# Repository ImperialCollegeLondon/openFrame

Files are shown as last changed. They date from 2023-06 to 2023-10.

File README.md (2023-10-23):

# Introduction to _openFrame_

This repository hosts information and instructions associated with the modular _openFrame_ microscope, a cost-effective platform based on open-hardware core components that can be configured or adapted to most light microscopy techniques and is intended to be used with open-source software, making instruments straightforward to maintain and to upgrade. _openFrame_ microscopes are based on stackable cylindrical aluminium layers centred on an optical axis that can accommodate a range of generic or specialised microscope components and which are ready to be mounted to external components such as optical cage systems. 
We are licensing the core _openFrame_ components under under the permissive version of the CERN Open Hardware License Version 2 ([https://ohwr.org/cern_ohl_p_v2.pdf](https://ohwr.org/cern_ohl_p_v2.pdf)), including the component designs hosted on this repository. We do not wish to restrict users in their ability to utilise _openFrame_ components and, as well as supporting the assembly of open instrumentation, openFrame components can be used with closed-source and proprietary technologies

Please see the ["How to cite openFrame" file](https://github.com/ImperialCollegeLondon/openFrame/blob/main/HOW%20TO%20CITE%20OPENFRAME.md) for information on how to cite _openFrame_

For further information on the modules that make up openFrame and associated information, please check the [wiki](https://github.com/ImperialCollegeLondon/openFrame/wiki) for this repository. 

## Where to find information

### [CAD designs](https://github.com/ImperialCollegeLondon/openFrame/tree/main/openFrame%20CAD)
The CAD files for the _openFrame_ components licensed under the permissive version of the CERN Open Hardware License Version 2 can be found in the folder called [_openFrame_ CAD](https://github.com/ImperialCollegeLondon/openFrame/tree/main/openFrame%20CAD). The [_openFrame_ part description PDFs](https://github.com/ImperialCollegeLondon/openFrame/tree/main/openFrame%20part%20description%20PDFs) folder contains important information such as hole tapping data, as well as suggested specification information relevant for fabrication of these components. 

### [Assembly instructions](https://github.com/ImperialCollegeLondon/openFrame/wiki)
As they become available, assembly instructions for creating an openFrame-based epifluorescence microscope will be found in the [wiki](https://github.com/ImperialCollegeLondon/openFrame/wiki) for this repo. Please note that as the system is modular and extensible, a much larger range of configurations are possible, but it is not feasible to document the assembly of every possible permutation. 

### Software
We make extensive use of [Micro-Manager](https://micro-manager.org/Version_2.0) to control _openFrame_ instrumentation but understand that this may not always be the first choice of all users or developers. Micro-Manager uses the Lesser GPL license ([https://www.gnu.org/licenses/lgpl-3.0.en.html](https://www.gnu.org/licenses/lgpl-3.0.en.html)) for its core and the BSD 2-clause license ([https://opensource.org/license/bsd-2-clause/](https://opensource.org/license/bsd-2-clause/)) for the GUI and device adapters, and any 
Micro-Manager device adapters we have written (for the openFrame hardware components licensed under the permissive version of the CERN Open Hardware License Version 2 in this repository) are licensed under the BSD 2-clause license.

Any other software for the open-source components _openFrame_ hardware components licensed under the permissive version of the CERN Open Hardware License Version 2 in this repository is licensed under the BSD 2-clause license ([https://opensource.org/license/bsd-2-clause/](https://opensource.org/license/bsd-2-clause/)). 

### Acknowledgements
The _openFrame_ is a compact, modular, open-source microscope conceived by Paul French and developed with colleagues from the [Photonics Group](https://www.imperial.ac.uk/photonics/) at [Imperial College London](https://www.imperial.ac.uk/), and then designed, supported, and extended in collaboration with [Cairn Research](https://www.cairn-research.co.uk/). The first prototype _openFrame_ microscope was co-designed and fabricated by Simon Johnson and Martin Kehoe in the Optics instrumentation facility of the Physics Department at Imperial College London with input. Subsequently the design and implementation were refined in a collaboration with Cairn Research Ltd by Frederik Görlitz and Sunil Kumar at Imperial supervised by Paul French, working with Callum Hollick at Cairn supervised by Jeremy Graham. Callum Hollick fabricated subsequent prototypes and designed the current version of core _openFrame_ components, which are represented in these CAD files.

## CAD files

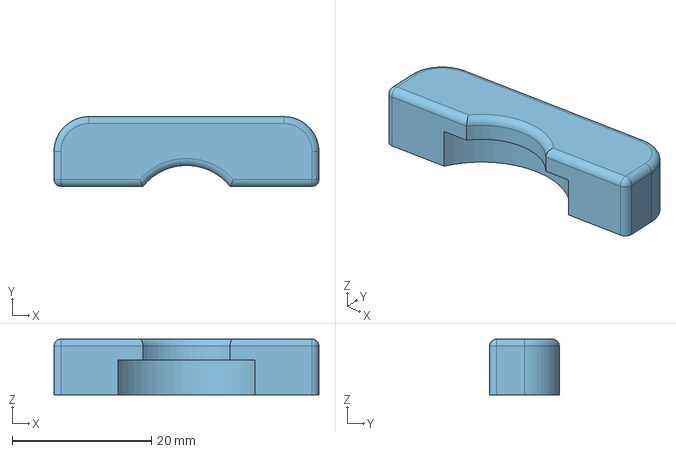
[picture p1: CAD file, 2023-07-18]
openFrame CAD/OF-HA-AC-00.stp
38.0 x 10.00 x 8.00 mm

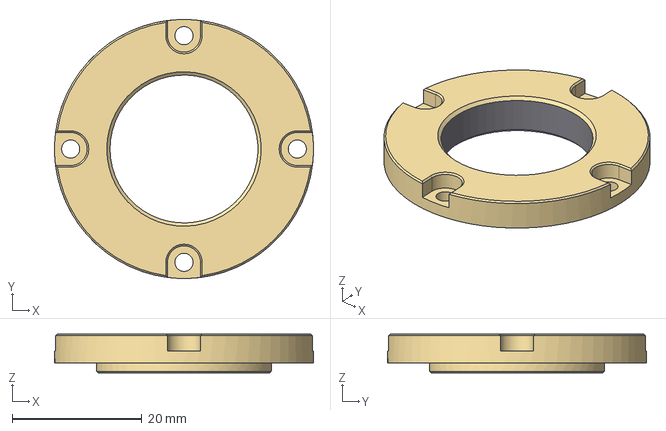
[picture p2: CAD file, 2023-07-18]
openFrame CAD/OF-AD-OBH-M25-60.stp
40.0 x 40.0 x 6.00 mm

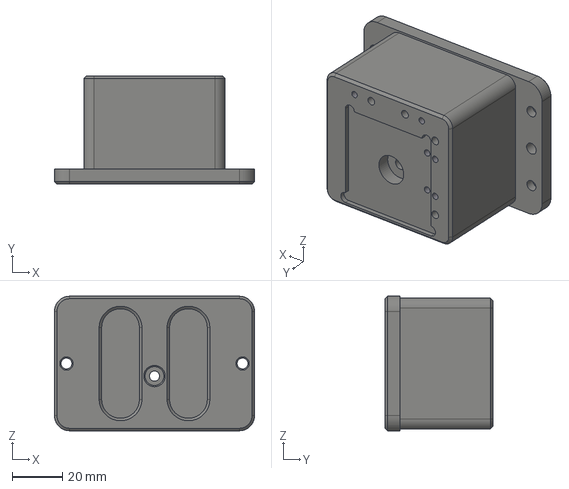
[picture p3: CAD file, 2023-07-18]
openFrame CAD/OF-IN-MCH.stp
79.5 x 43.0 x 53.5 mm

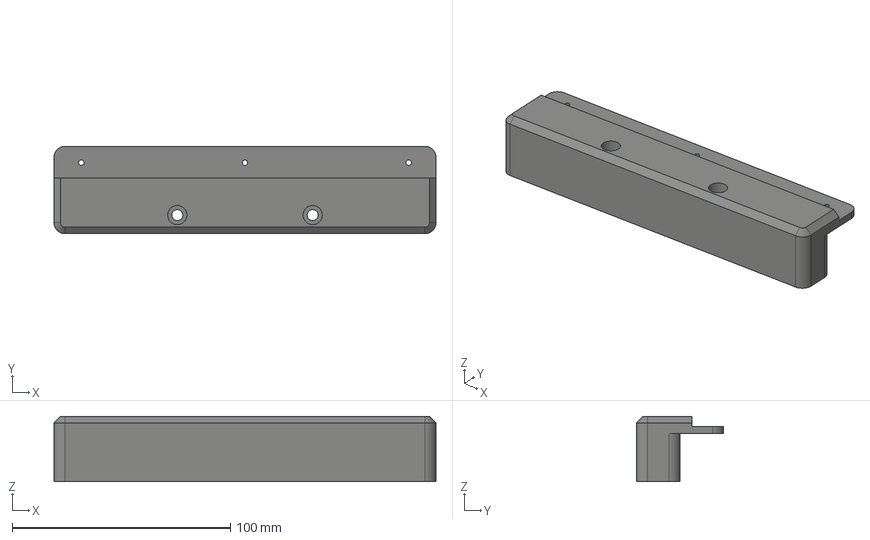
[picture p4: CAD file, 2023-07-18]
openFrame CAD/OF-AD-SP-ZAB-PZ-PI-Q545.stp
175.0 x 40.0 x 30.0 mm

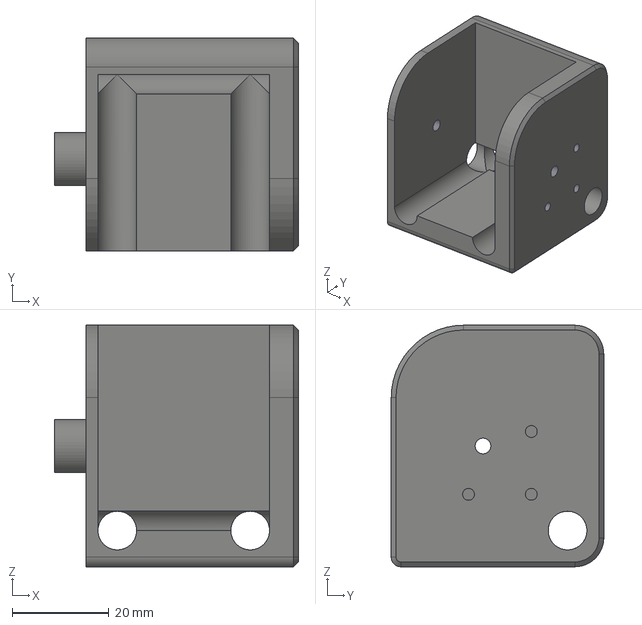
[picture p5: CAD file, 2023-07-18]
openFrame CAD/OF-AD-MCH-M45.stp
50.5 x 44.0 x 50.0 mm

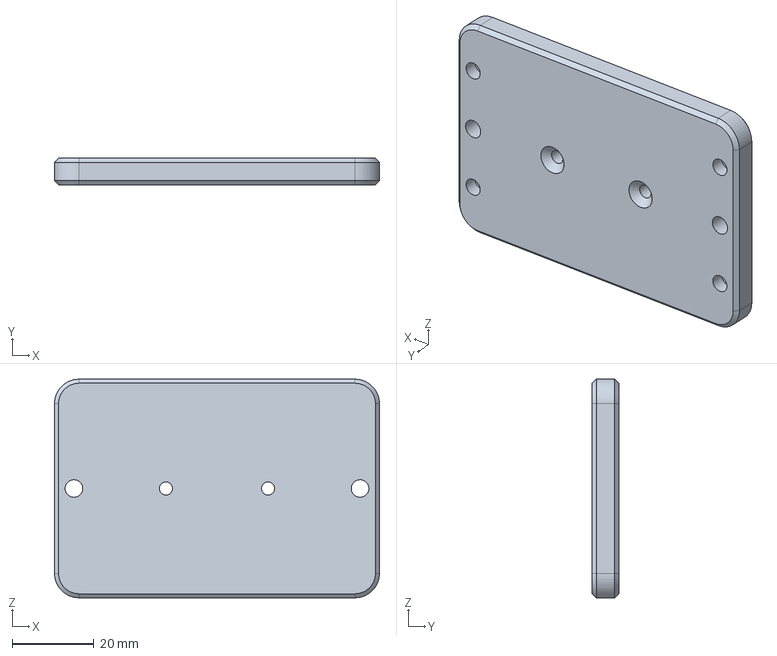
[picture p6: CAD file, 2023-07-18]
openFrame CAD/OF-AC-00.stp
79.5 x 6.50 x 53.5 mm

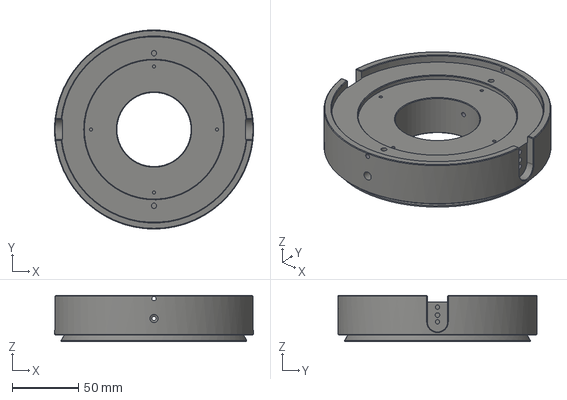
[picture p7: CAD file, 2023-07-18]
openFrame CAD/OF-LL-TL.stp
150.0 x 150.0 x 35.0 mm

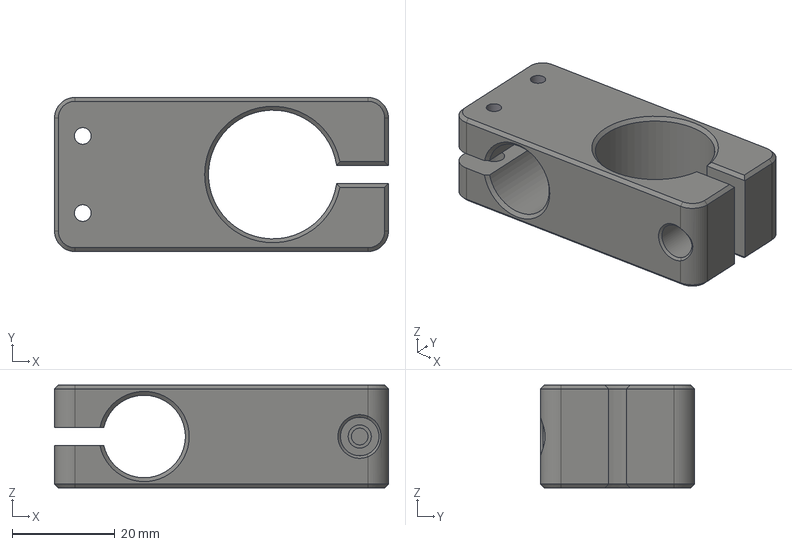
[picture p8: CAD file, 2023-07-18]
openFrame CAD/OF-AD-TI-PILLAR-TI-ARM.stp
65.0 x 30.0 x 20.0 mm

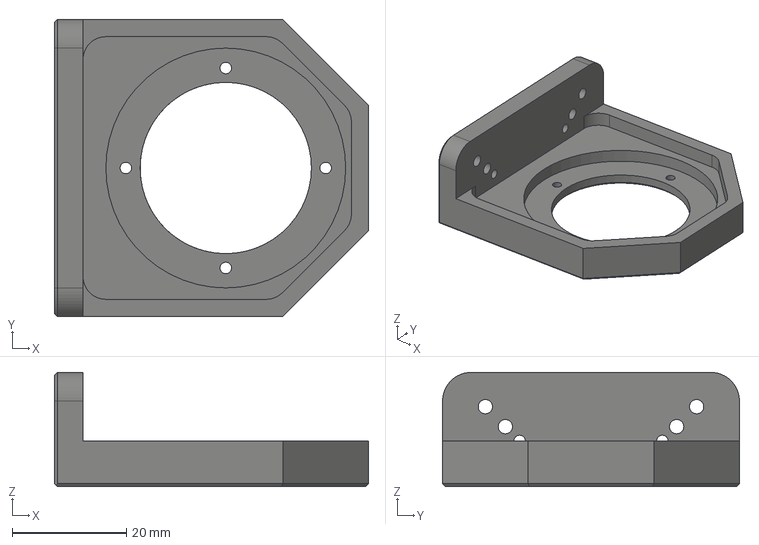
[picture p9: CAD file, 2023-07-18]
openFrame CAD/OF-AD-PZ-PI-Q545-OBH.stp
55.0 x 52.0 x 20.0 mm

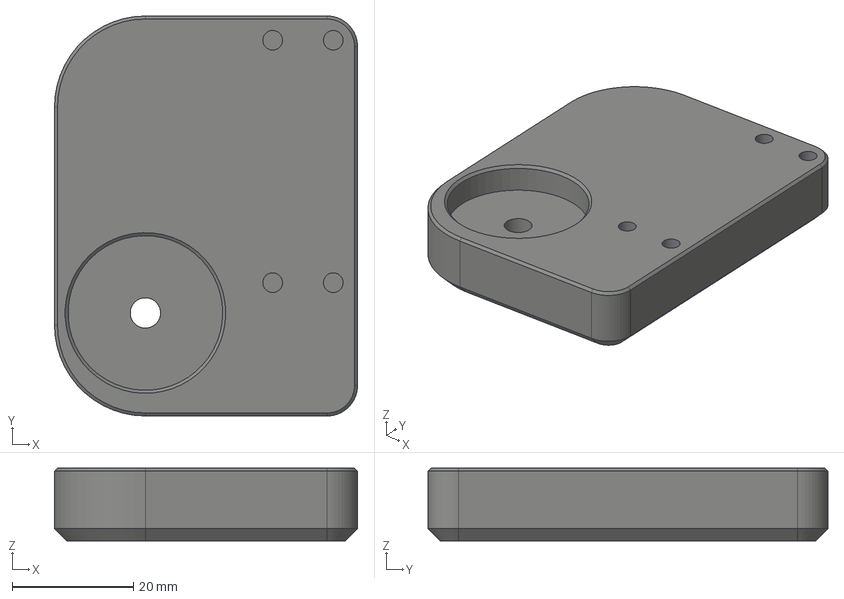
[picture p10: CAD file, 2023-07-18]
openFrame CAD/OF-AD-SP-TI-PILLAR.stp
50.0 x 66.0 x 12.0 mm

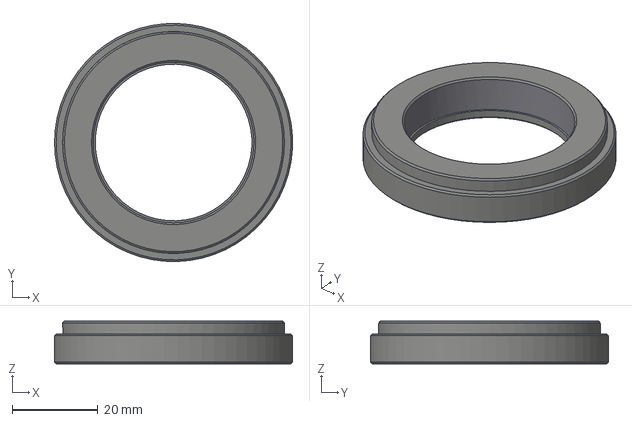
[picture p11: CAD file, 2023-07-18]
openFrame CAD/OF-AD-SM2-TL-NIKON.stp
55.5 x 55.5 x 10.0 mm

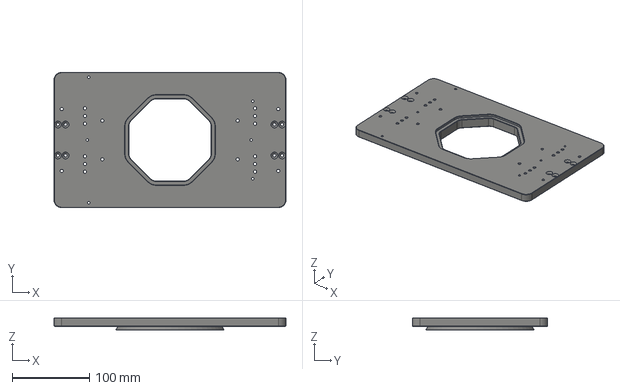
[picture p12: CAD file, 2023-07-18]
openFrame CAD/OF-LL-SP.stp
300.0 x 175.0 x 16.0 mm

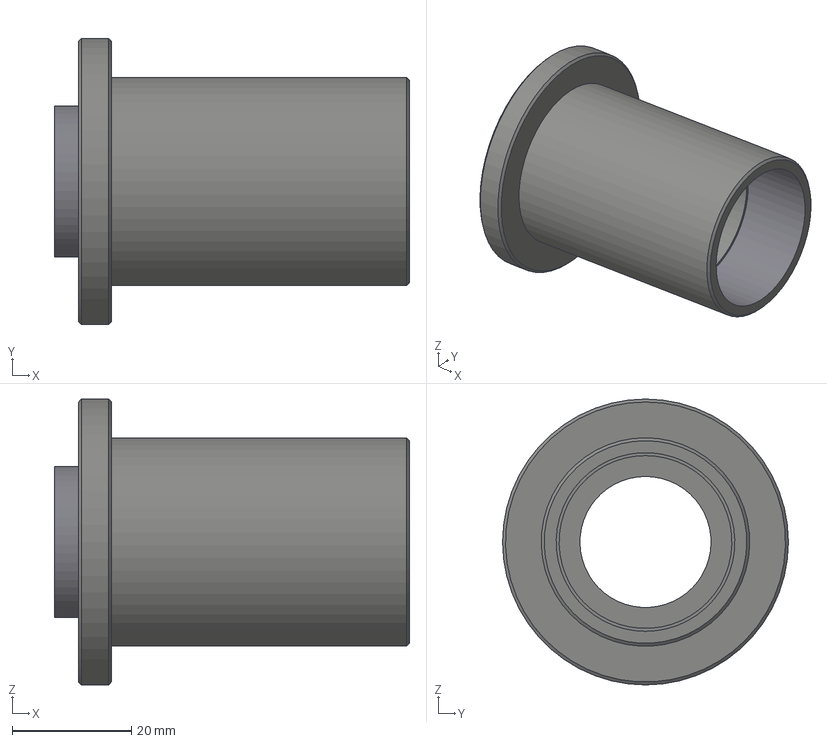
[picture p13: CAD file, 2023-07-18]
openFrame CAD/OF-AD-SBSM30-CM.stp
59.6 x 48.0 x 48.0 mm

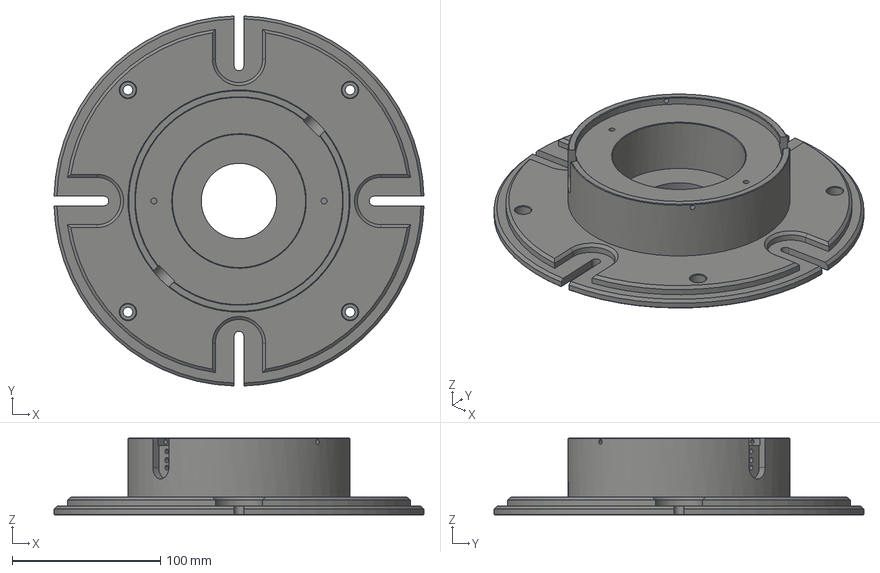
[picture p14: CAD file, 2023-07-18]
openFrame CAD/OF-LL-BP.stp
249.9 x 249.9 x 52.0 mm

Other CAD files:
openFrame CAD/OF-PP-SM30.stp
openFrame CAD/OF-AD-TI-ARM-LED-CAIRN.stp
openFrame CAD/OF-AD-SM2-TL-OLYMPUS.stp
openFrame CAD/OF-AD-LL-SM1.stp
openFrame CAD/OF-AC-2P-OD.stp
openFrame CAD/OF-AD-FL-PZ-PI-Q545.stp
openFrame CAD/OF-AD-HA-IN-2P-OD.stp
openFrame CAD/OF-AD-OBH-RMS-45.stp
openFrame CAD/OF-AD-SBSM2-CM.stp
openFrame CAD/OF-CL-LC.stp
openFrame CAD/OF-CL-SM2.stp
openFrame CAD/OF-CL-SM30.stp
openFrame CAD/OF-HA-2P-OD.stp
openFrame CAD/OF-IN-2P-OD.stp
openFrame CAD/OF-LL-65.stp
openFrame CAD/OF-LL-80.stp
openFrame CAD/OF-LL-FL-MOT.stp
openFrame CAD/OF-PP-SM2.stp
openFrame CAD/OF-TI-ARM.step
openFrame CAD/OF-TI-PILLAR.step

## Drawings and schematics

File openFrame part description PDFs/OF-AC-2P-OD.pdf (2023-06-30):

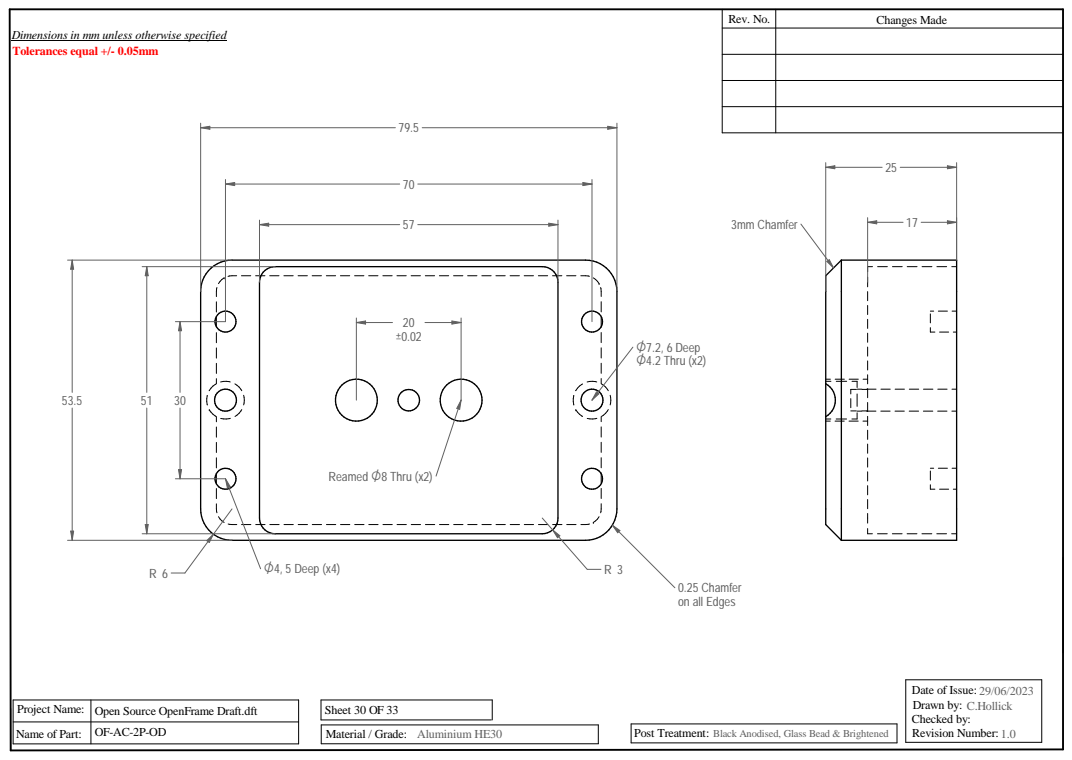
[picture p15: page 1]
Project Name:; Material / Grade:; Post Treatment:; Open Source OpenFrame Draft.dft; Sheet 30 OF 33; Rev. No.; Changes Made; O4, 5 Deep (x4); O7.2, 6 Deep O4.2 Thru (x2); 3mm Chamfer; Reamed O8 Thru (x2); Aluminium HE30; Black Anodised, Glass Bead & Brightened; C.Hollick

Dimensions in mm unless otherwise specified
Tolerances equal +/- 0.05mm

0.25 Chamfer
on all Edges

Date of Issue:
Drawn by:
Checked by:
Revision Number:

Name of Part:

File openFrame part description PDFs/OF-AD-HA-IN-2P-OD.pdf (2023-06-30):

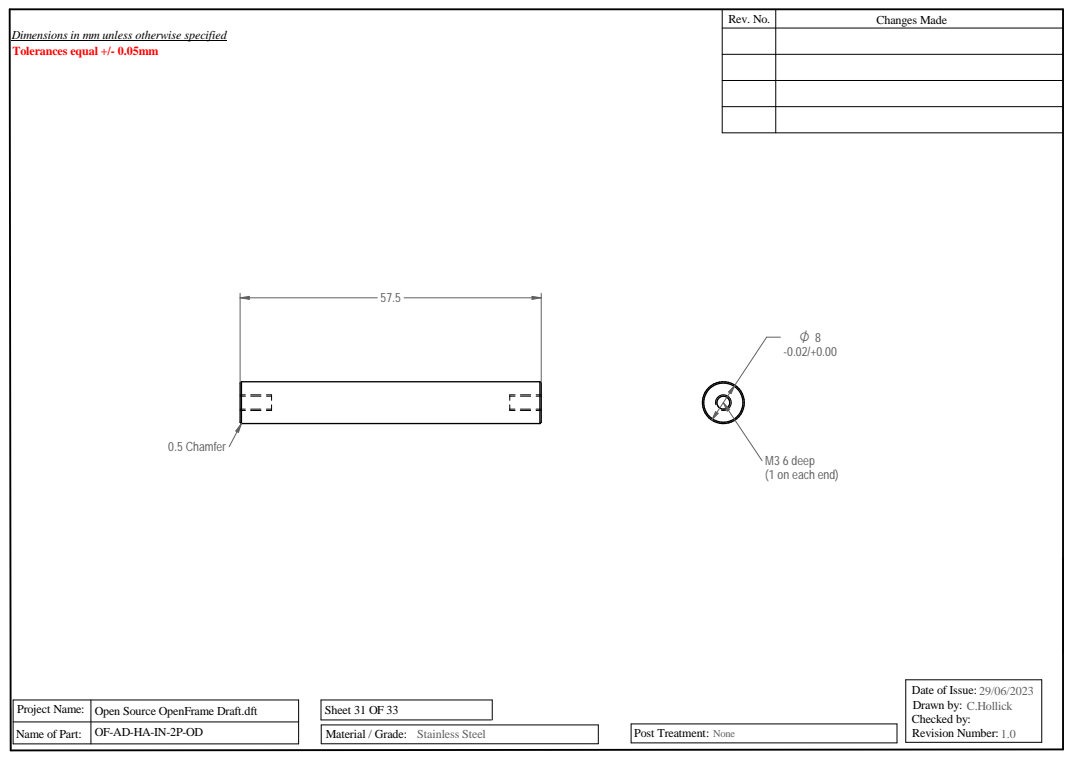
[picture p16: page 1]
Project Name:; Material / Grade:; Post Treatment:; Open Source OpenFrame Draft.dft; Sheet 31 OF 33; Rev. No.; Changes Made; 0.5 Chamfer; Stainless Steel; None; C.Hollick

Dimensions in mm unless otherwise specified
Tolerances equal +/- 0.05mm

M3 6 deep
(1 on each end)

Date of Issue:
Drawn by:
Checked by:
Revision Number:

Name of Part:

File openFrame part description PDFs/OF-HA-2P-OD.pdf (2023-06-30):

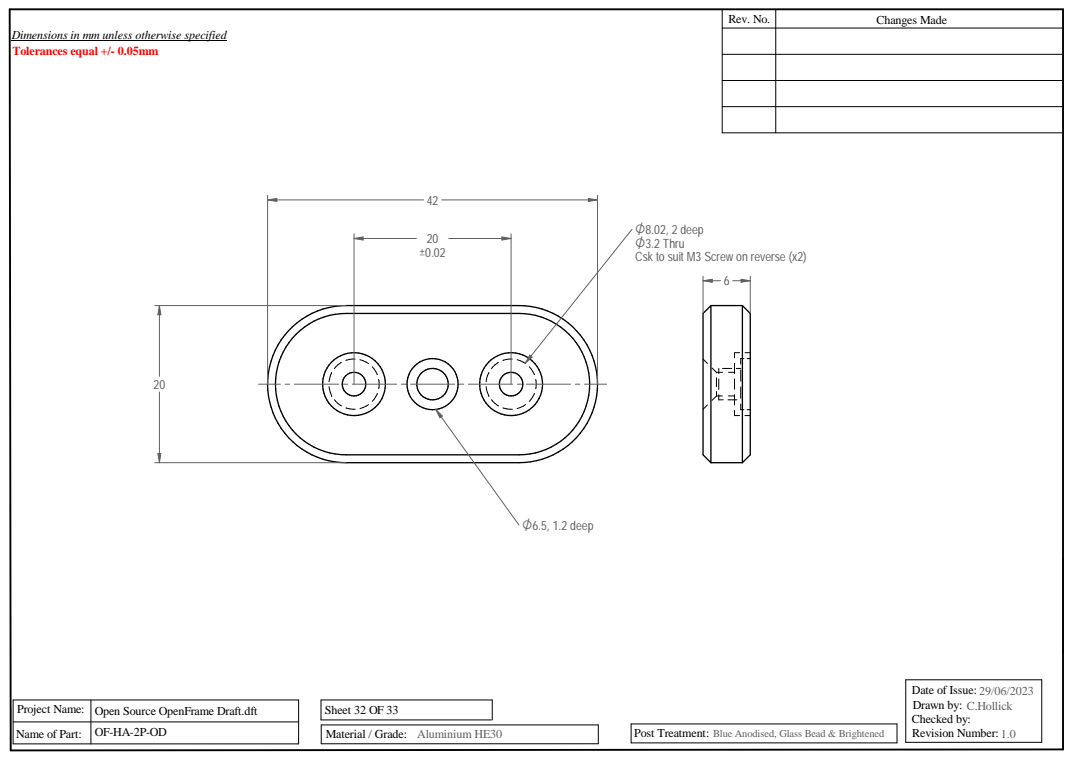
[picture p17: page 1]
Project Name:; Material / Grade:; Post Treatment:; Open Source OpenFrame Draft.dft; Sheet 32 OF 33; Rev. No.; Changes Made; O8.02, 2 deep O3.2 Thru; O6.5, 1.2 deep; Aluminium HE30; Blue Anodised, Glass Bead & Brightened; C.Hollick

Dimensions in mm unless otherwise specified
Tolerances equal +/- 0.05mm

Csk to suit M3 Screw on reverse (x2)

Date of Issue:
Drawn by:
Checked by:
Revision Number:

Name of Part:

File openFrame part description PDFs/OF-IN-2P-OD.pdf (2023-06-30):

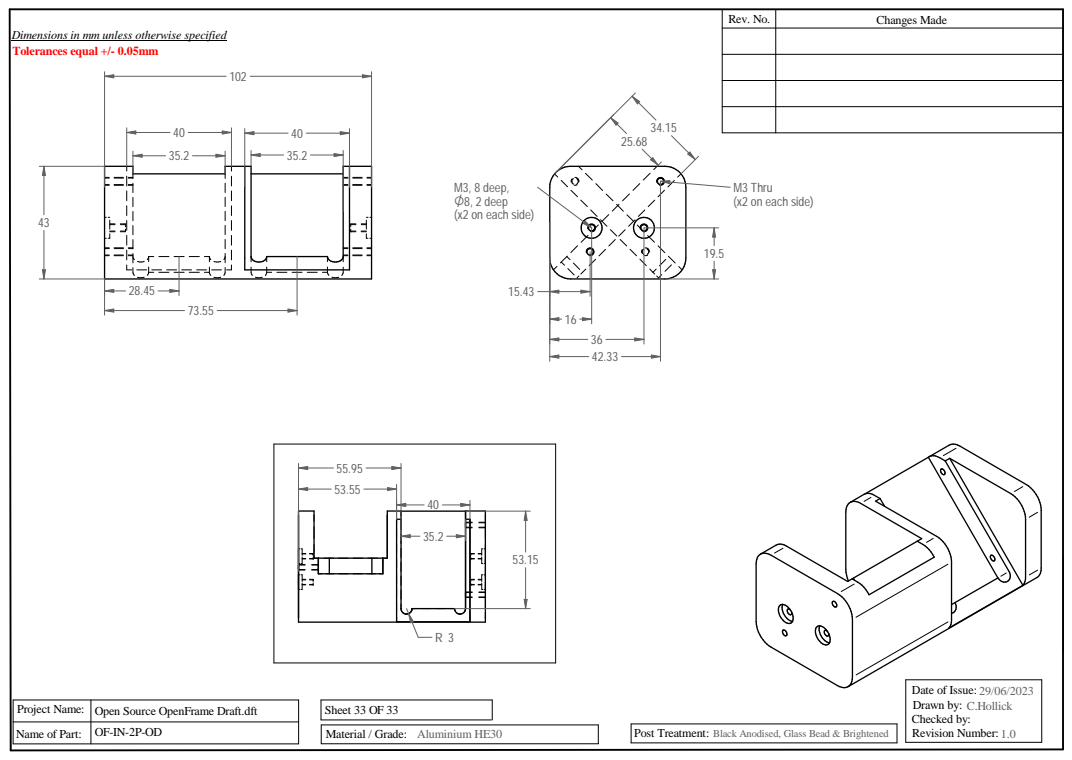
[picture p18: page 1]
Project Name:; Material / Grade:; Post Treatment:; Open Source OpenFrame Draft.dft; Sheet 33 OF 33; Rev. No.; Changes Made; Aluminium HE30; Black Anodised, Glass Bead & Brightened; C.Hollick; M3, 8 deep, O8, 2 deep

Dimensions in mm unless otherwise specified
Tolerances equal +/- 0.05mm

M3 Thru
(x2 on each side)

Date of Issue:
Drawn by:
Checked by:
Revision Number:

Name of Part:

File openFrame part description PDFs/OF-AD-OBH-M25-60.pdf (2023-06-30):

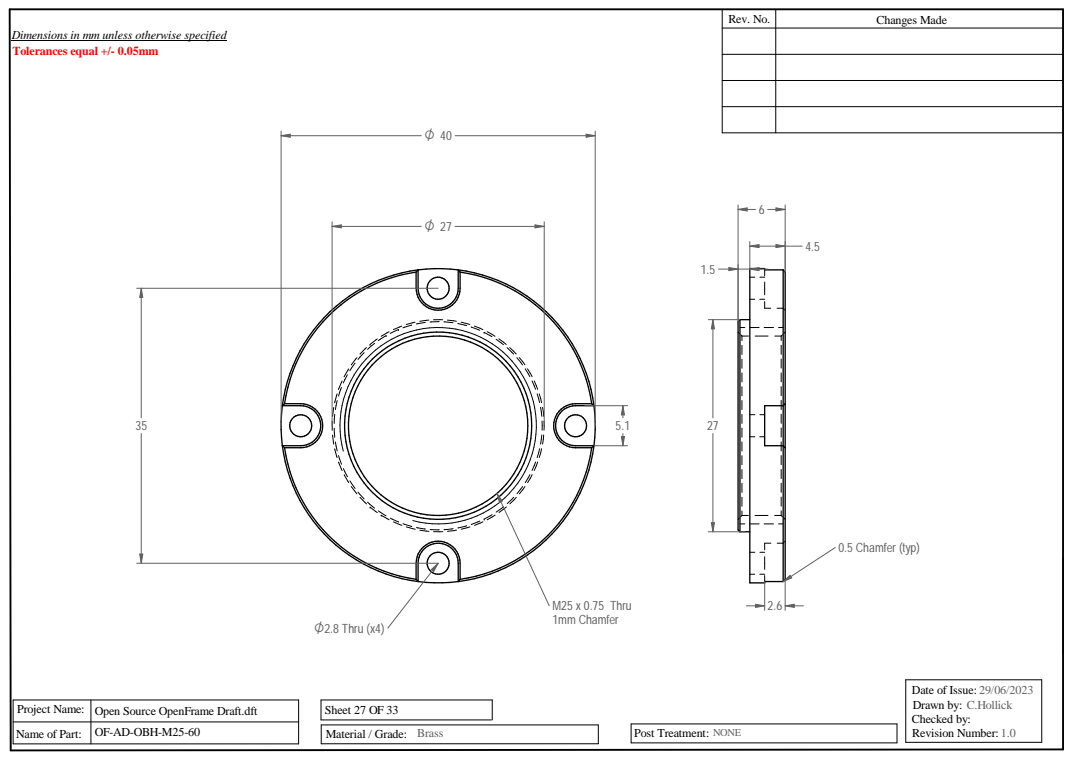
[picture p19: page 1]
Project Name:; OF-AD-OBH-M25-60; Material / Grade:; Post Treatment:; Open Source OpenFrame Draft.dft; Sheet 27 OF 33; Rev. No.; Changes Made; Brass; NONE; C.Hollick; O2.8 Thru (x4); M25 x 0.75 Thru 1mm Chamfer; 0.5 Chamfer (typ)

Dimensions in mm unless otherwise specified
Tolerances equal +/- 0.05mm

Date of Issue:
Drawn by:
Checked by:
Revision Number:

Name of Part:

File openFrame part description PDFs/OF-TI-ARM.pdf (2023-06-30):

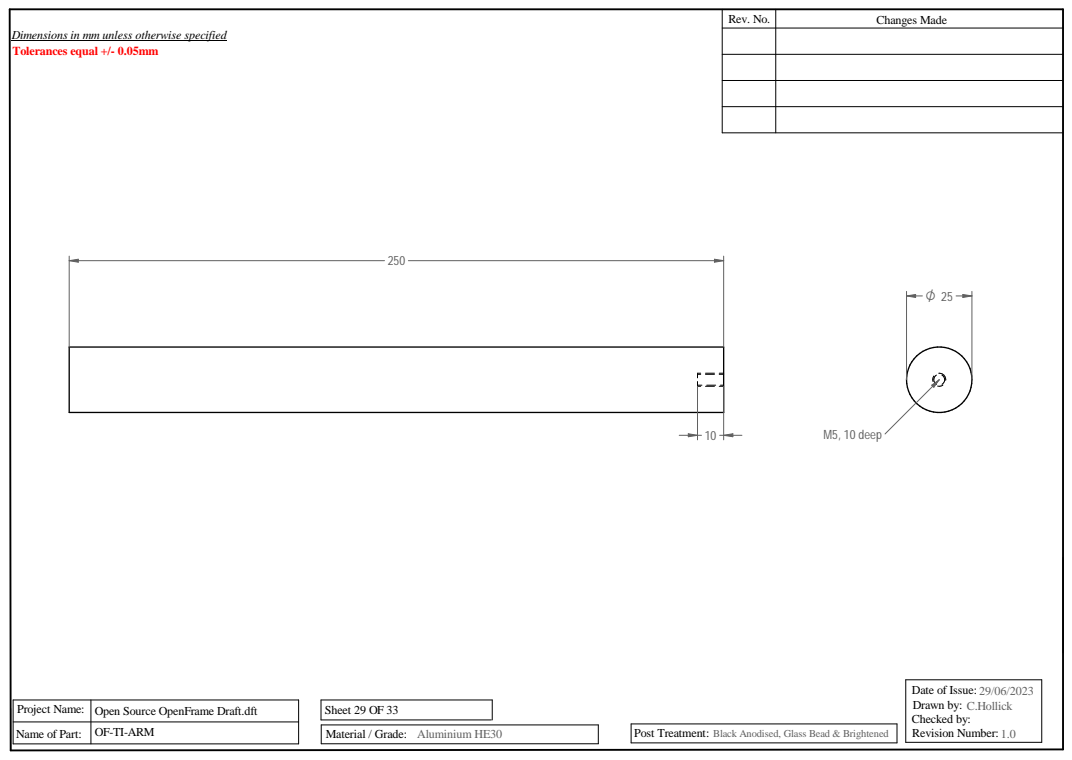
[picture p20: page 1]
Project Name:; OF-TI-ARM; Material / Grade:; Post Treatment:; Open Source OpenFrame Draft.dft; Sheet 29 OF 33; Rev. No.; Changes Made; M5, 10 deep; Aluminium HE30; Black Anodised, Glass Bead & Brightened; C.Hollick

Dimensions in mm unless otherwise specified
Tolerances equal +/- 0.05mm

Date of Issue:
Drawn by:
Checked by:
Revision Number:

Name of Part:

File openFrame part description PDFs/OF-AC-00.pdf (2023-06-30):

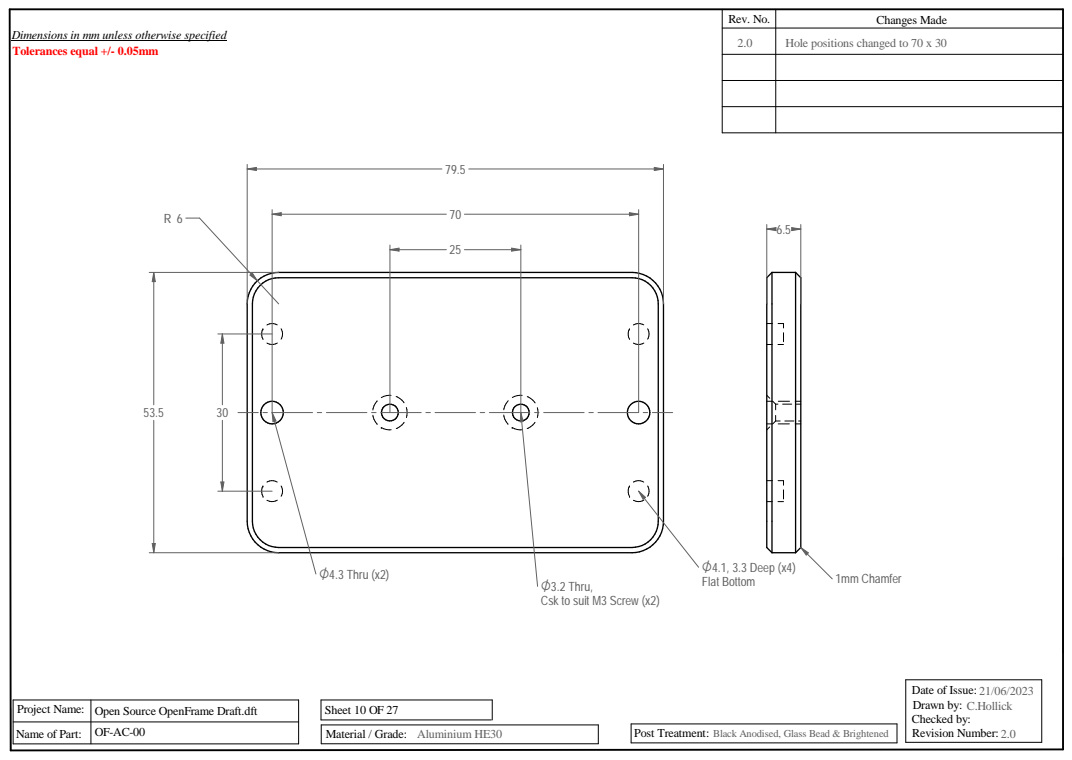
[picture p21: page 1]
Project Name:; Material / Grade:; Post Treatment:; Open Source OpenFrame Draft.dft; Sheet 10 OF 27; O4.1, 3.3 Deep (x4); Flat Bottom O4.3 Thru (x2); O3.2 Thru,; 1mm Chamfer; Aluminium HE30; Black Anodised, Glass Bead & Brightened; C.Hollick

Rev. No. | Changes Made

Dimensions in mm unless otherwise specified
Tolerances equal +/- 0.05mm

2.0 | Hole positions changed to 70 x 30

Csk to suit M3 Screw (x2)

Date of Issue:
Drawn by:
Checked by:
Revision Number:

Name of Part:

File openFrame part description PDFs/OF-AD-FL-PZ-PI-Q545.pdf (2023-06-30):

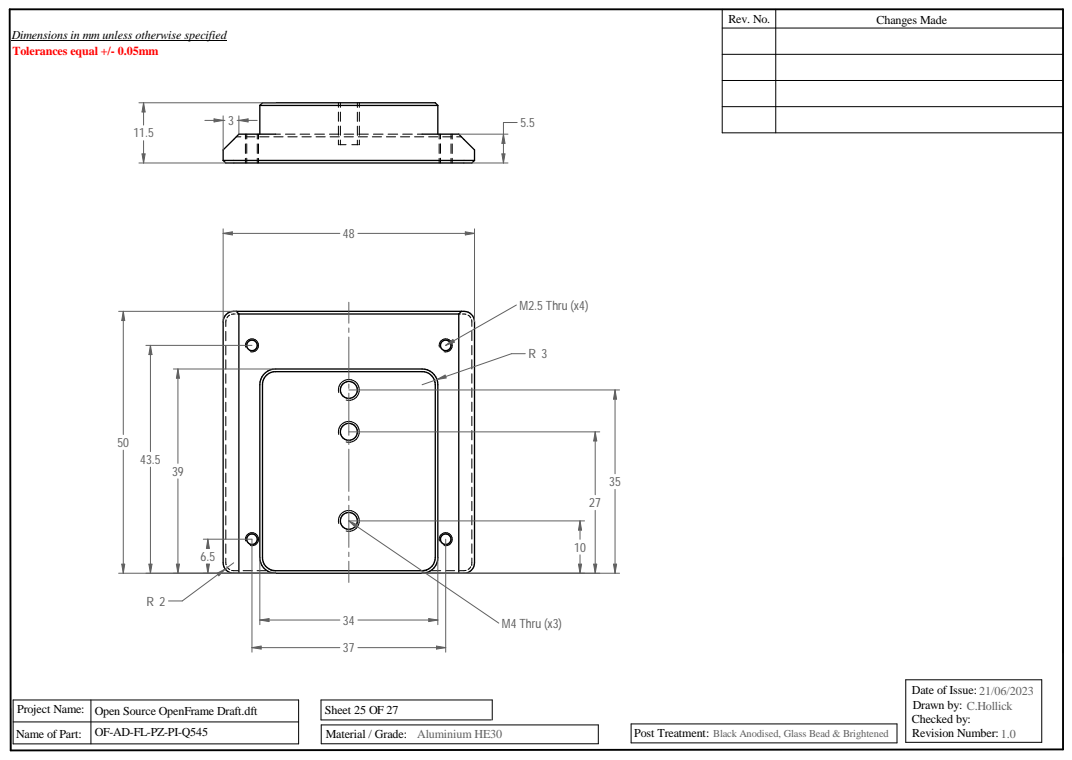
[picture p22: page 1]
Project Name:; Material / Grade:; Post Treatment:; Open Source OpenFrame Draft.dft; Sheet 25 OF 27; Rev. No.; Changes Made; M2.5 Thru (x4); M4 Thru (x3); Aluminium HE30; Black Anodised, Glass Bead & Brightened; C.Hollick

Dimensions in mm unless otherwise specified
Tolerances equal +/- 0.05mm

Date of Issue:
Drawn by:
Checked by:
Revision Number:

Name of Part:

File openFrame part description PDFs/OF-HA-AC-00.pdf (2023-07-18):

# Dimensions in mm unless otherwise specified Tolerances equal +/- 0.05mm

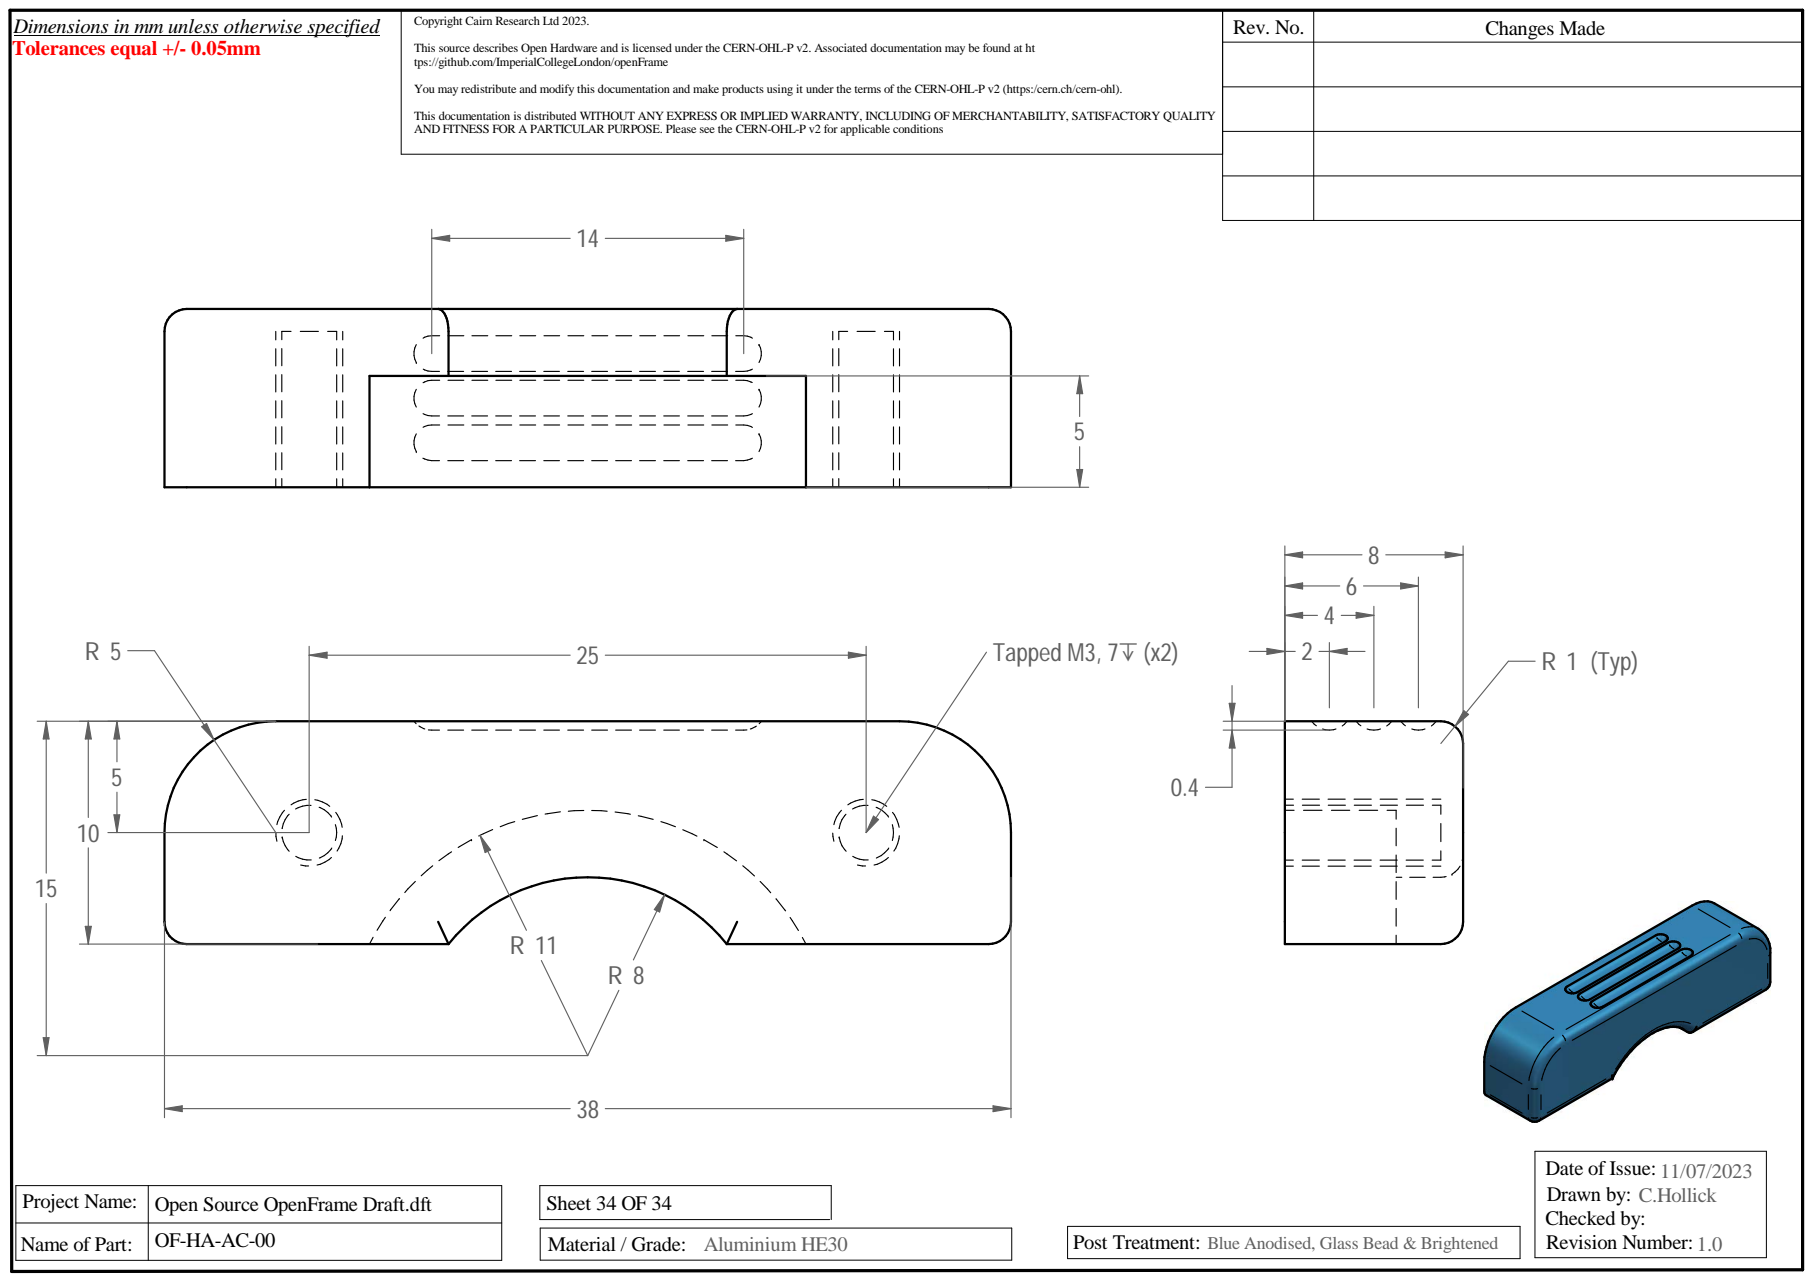
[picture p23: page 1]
Project Name:; Material / Grade:; Post Treatment:; Open Source OpenFrame Draft.dft; Sheet 34 OF 34; Rev. No.; Changes Made Copyright Cairn Research Ltd 2023.; Tapped M3, 7` (x2); R 1 (Typ) 25; Aluminium HE30; Blue Anodised, Glass Bead & Brightened; C.Hollick

This source describes Open Hardware and is licensed under the CERN-OHL-P v2. Associated documentation may be found at ht
tps://github.com/ImperialCollegeLondon/openFrame

You may redistribute and modify this documentation and make products using it under the terms of the CERN-OHL-P v2 (https:/cern.ch/cern-ohl).

This documentation is distributed WITHOUT ANY EXPRESS OR IMPLIED WARRANTY, INCLUDING OF MERCHANTABILITY, SATISFACTORY QUALITY
AND FITNESS FOR A PARTICULAR PURPOSE. Please see the CERN-OHL-P v2 for applicable conditions

Date of Issue:
Drawn by:
Checked by:
Revision Number:

Name of Part:

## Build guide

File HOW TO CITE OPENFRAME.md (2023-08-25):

# How to cite _openFrame_

This page will provide a list of suitable items for citing as a reference to _openFrame_-derived equipment.

This article to be published in the Journal of Microscopy is the preferred reference to use in any publication:
[openFrame: A modular, sustainable, open microscopy platform with single-shot, dual-axis optical autofocus module providing high precision and long range of operation](https://doi.org/10.1111/jmi.13219)

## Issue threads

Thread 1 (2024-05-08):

Desig Files available, too?

beniroquai, 2024-05-08:
Hey @SK-UK, great project! I really appreciate this!! I have downloaded the STP files and tried to interact with them a bit. I was wondering if you had the modifiable designfiles as well. I use inventor, but typically one can convert from e.g. Solidworks to Iventor or Fusion360. Thanks a lot! :-)

pmwf, 2024-05-11:
Hi Benedict,

Good to catch up with you at Janelia.

Sunil will have to answer this. I am not clear about limitations of CAD files.

Best wishes,

Paul

(If I email you out of normal working hours, I would not expect any response before your next working day)

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

SK-UK, 2024-05-14:
Hi Benedict,

There is a Work-In-Progress effort to make designs for all the components in OnShape that can be found here:
https://cad.onshape.com/documents/3b48c6a8511b1b43c7bff627/w/7d6b863b3b5475129e35c451/e/34bea7accd4a352a9b473443

Once these designs are complete on an open platform, they'll be linked from this repo. For now though, please double-check anything on OnShape against the files here before using it!

Regards,
Sunil

beniroquai, 2024-05-14:
Thanks a lot! I will catch up with the printer once I'm back in Germany :-)

Closed 2024-05-14.

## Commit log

2023-06-29 Added CAD files
    Initial commit of CAD files
    [OF-AC-00.stp, OF-AD-FL-PZ-PI-Q545.stp, OF-AD-LL-SM1.stp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]
2023-07-11 Updated CAD files to have OHWL v2 info in them
    [OF-AC-00.stp, OF-AC-2P-OD.stp, OF-AD-FL-PZ-PI-Q545.stp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]
2023-07-18 Fix diff issue
    [OF-AC-00.stp, OF-AC-2P-OD.stp, OF-AD-FL-PZ-PI-Q545.stp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]
2023-07-18 Readd CAD
    [OF-AC-00.stp, OF-AC-2P-OD.stp, OF-AD-FL-PZ-PI-Q545.stp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]
2023-07-18 Added more CAD
    [OF-AD-OBH-M25-60.stp, OF-HA-AC-00.stp]
2023-08-03 Update README.md
    Corrected license/link for device adapters

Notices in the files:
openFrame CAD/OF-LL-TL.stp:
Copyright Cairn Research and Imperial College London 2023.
